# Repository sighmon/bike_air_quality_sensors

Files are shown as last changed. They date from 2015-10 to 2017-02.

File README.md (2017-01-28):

# Bike air quality sensors

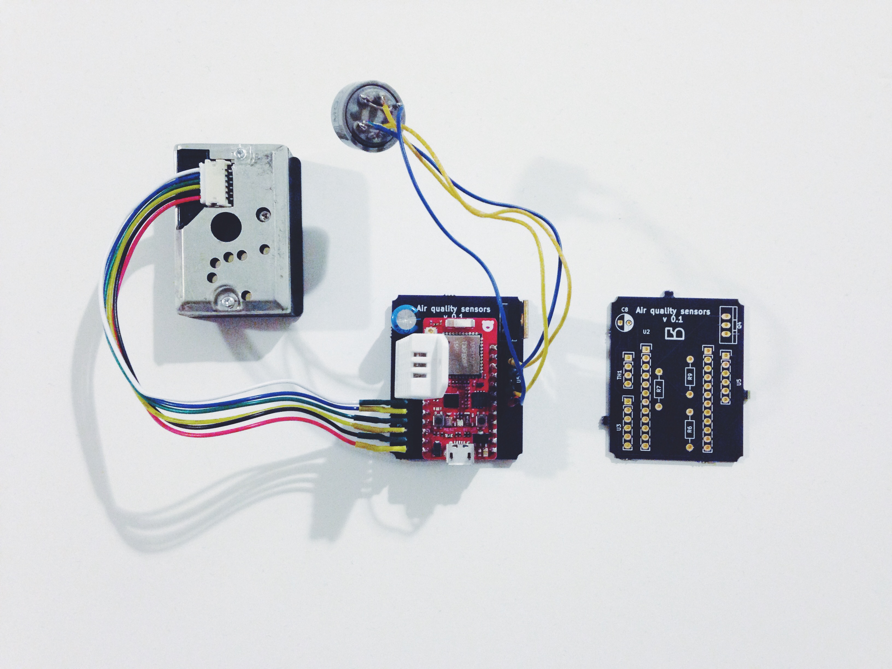
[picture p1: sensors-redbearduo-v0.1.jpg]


A set of Carbon Monoxide & dust particle sensors combined with humidity/temperature sensors for measuring the air quality while cycling.

The sensors are hooked up to an Arduino which then sends the data via serial over Bluetooth to our Android or iOS phone to be time stamped and have GPS data added.

This data will then be sent to a Rails server to graph the data - and also provide an API for others to interact with it.

by Damien & Simon

## Hardware

* [Redbear Duo](https://github.com/redbear/Duo)
* [MQ-7 Carbon Monoxide sensor](https://www.sparkfun.com/products/9403)
* [GP2Y10 Dust Particle sensor](https://www.sparkfun.com/products/9689)
* [DHT-22 Temperature/Humidity sensor](https://www.sparkfun.com/products/10167)
* P-channel MOSFET
* 10K ohm resistor
* 20K ohm resistor
* 150 ohm resistor
* 220µF capacitor

## Output

The sensors are read every second and output in a struct:

`struct SENSOR_READINGS {
    float temperature;
    float humidity;
    float particles;
    float co;
    char heaterOn;
};`

* Temperature in Celsius
* Humidity %
* Dust particle raw sensor value
* Carbon monoxide raw sensor value
* Heater on/off sent as 1 or 0

### Power usage

* When heating the Carbon Monoxide sensor: 200 mA
* When not heating the Carbon Monoxide sensor: 130 mA

### Data from the iOS app with GPS location & timestamp

Google Spreadsheet: [bike sensor data](https://docs.google.com/spreadsheets/d/1QTtR4N6sVxgsv6Za4kGe6Mn_MdasWhGjeMLYdR82Do4/edit?usp=sharing)

[Interactive graph of the data](https://docs.google.com/spreadsheets/d/1QTtR4N6sVxgsv6Za4kGe6Mn_MdasWhGjeMLYdR82Do4/pubchart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)

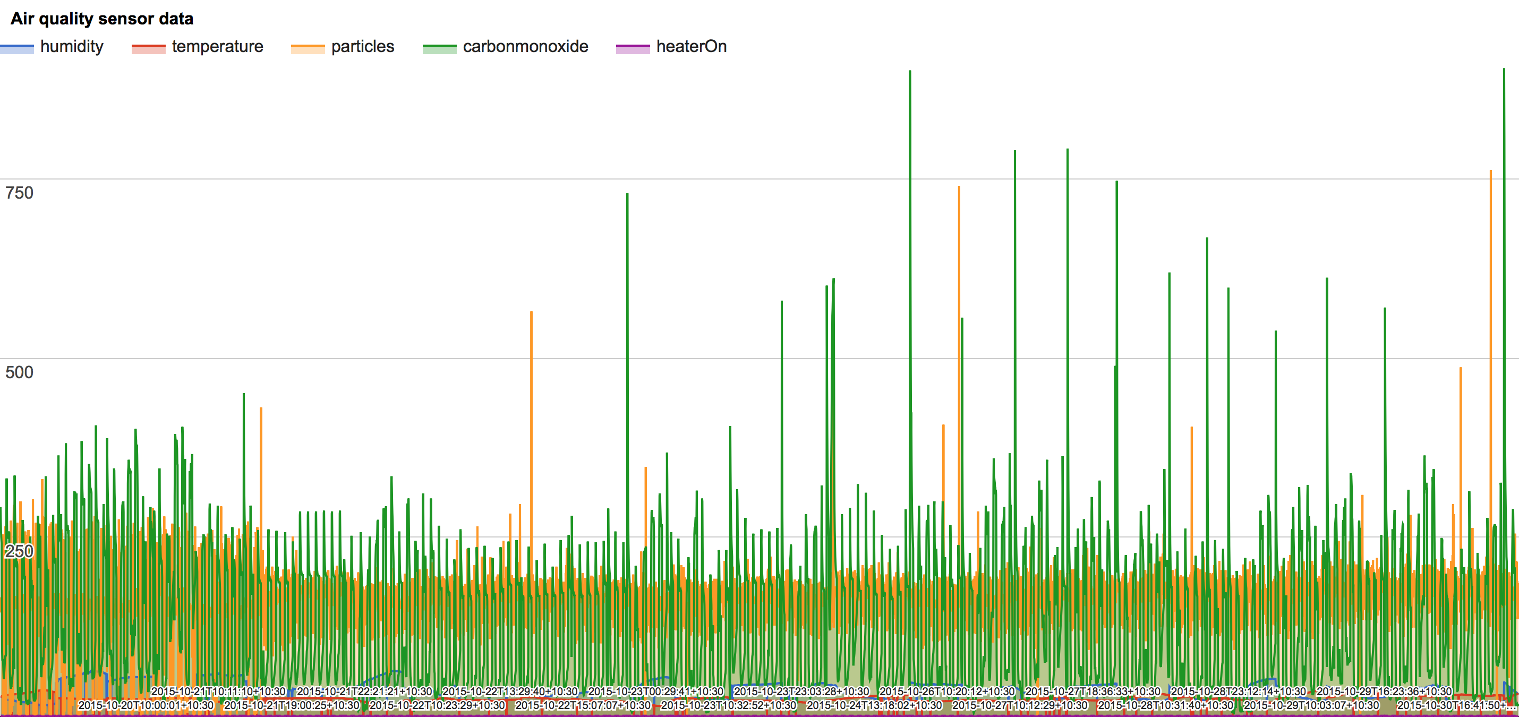
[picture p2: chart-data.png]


## Libraries

Thanks for the DHT sensor library:
<https://learn.adafruit.com/dht/using-a-dhtxx-sensor>

Thanks for the Sharp Optical Dust Sensor library:
<http://arduinodev.woofex.net/2012/12/01/standalone-sharp-dust-sensor/>

MQ-7 Carbon Monoxide sensor:
<http://thesis.jmsaavedra.com/make/>

## iOS & Android apps

[iOS app](https://github.com/sighmon/BikeAirQualitySensorsiOS)

[Android app](https://github.com/33d/bike-air-sensor-logger)

Both apps add:

* ISO 8601 formatted time, including the time zone.
* The position - latitude and longitude.

Then they export the data to a CSV file.

## Python data parser for the CSV

The Carbon Monoxide sensor can only be read after it's been heating for 60 seconds, so we need to throw away all of the data around this.

This Python parser does just that. :-)

<https://github.com/sighmon/bike_air_quality_sensor_csv_parser>

## Manufactured by OSH Park

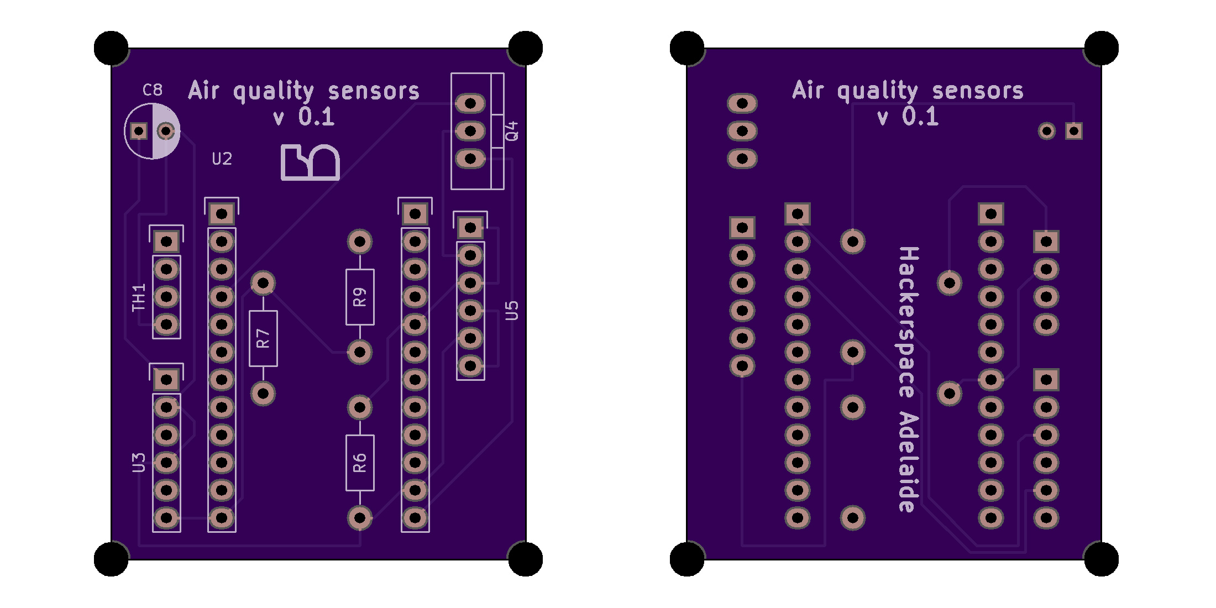
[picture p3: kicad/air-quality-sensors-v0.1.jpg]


I got the first batch of boards manufactured by <https://oshpark.com>. You can see the shared project here: <https://oshpark.com/profiles/sighmon>

## GovHack Machinery of Data entry video

<iframe width="100%" height="315" src="https://www.youtube.com/embed/KiIhrwRlb6w" frameborder="0" allowfullscreen></iframe>

## Troubleshooting

- If the RedBear Duo gets itself into a flashing blue light of doom, hold down both ```reset + setup``` for 3 seconds, then let go of the reset. Hold the setup button until the flashing turns yellow. That’s DFU mode to [re-upload the user firmware](https://github.com/redbear/Duo/blob/master/docs/firmware_deployment_guide.md).

``` $ dfu-util -d 2b04:d058 -a 0 -s 0x80C0000 -D duo-user-part.bin```

## TODO

* <s>Connect sensors to the Arduino.</s>
* <s>Send data via Bluetooth.</s>
* <s>Build an iOS app.</s>
* <s>Build an Android app.</s>
* Build a Rails server to open up the data via a public API.

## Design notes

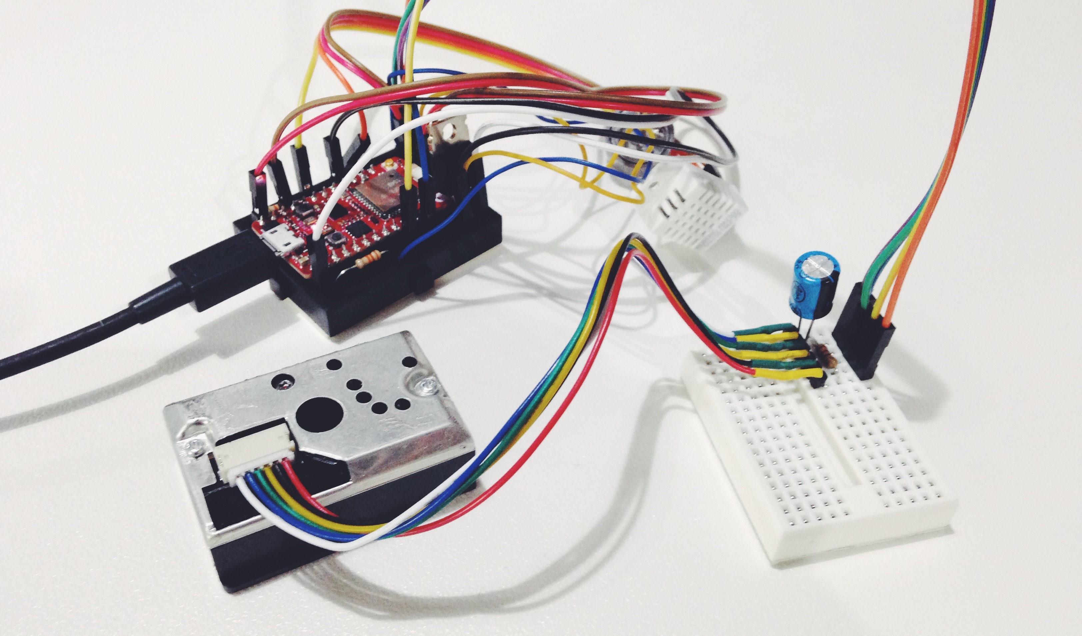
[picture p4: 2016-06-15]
sensors-redbearduo.jpg

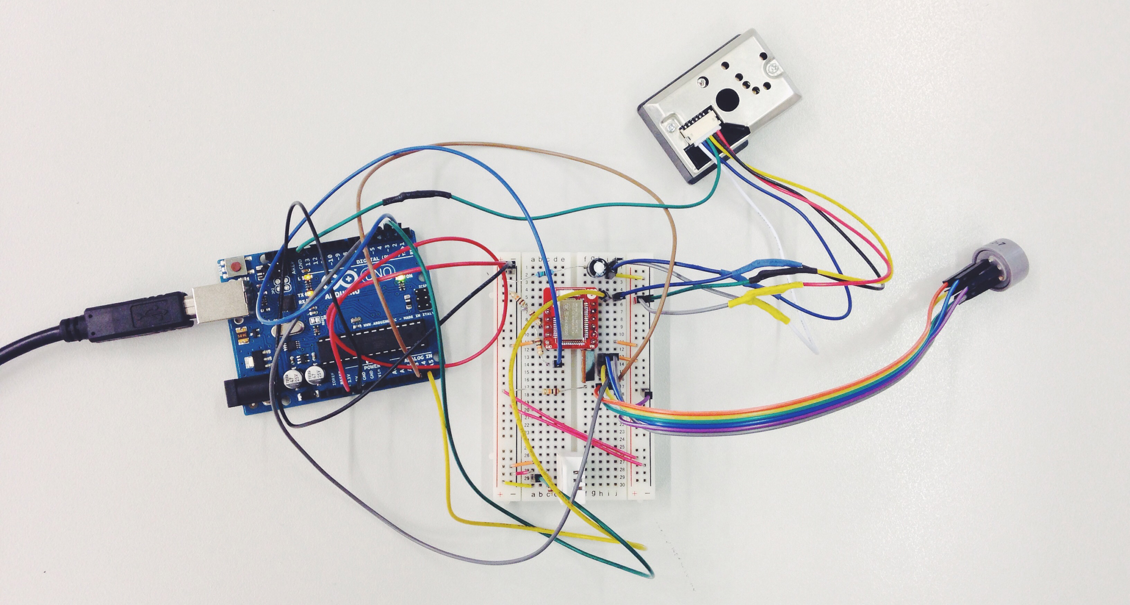
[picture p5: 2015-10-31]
sensors-arduino.jpg

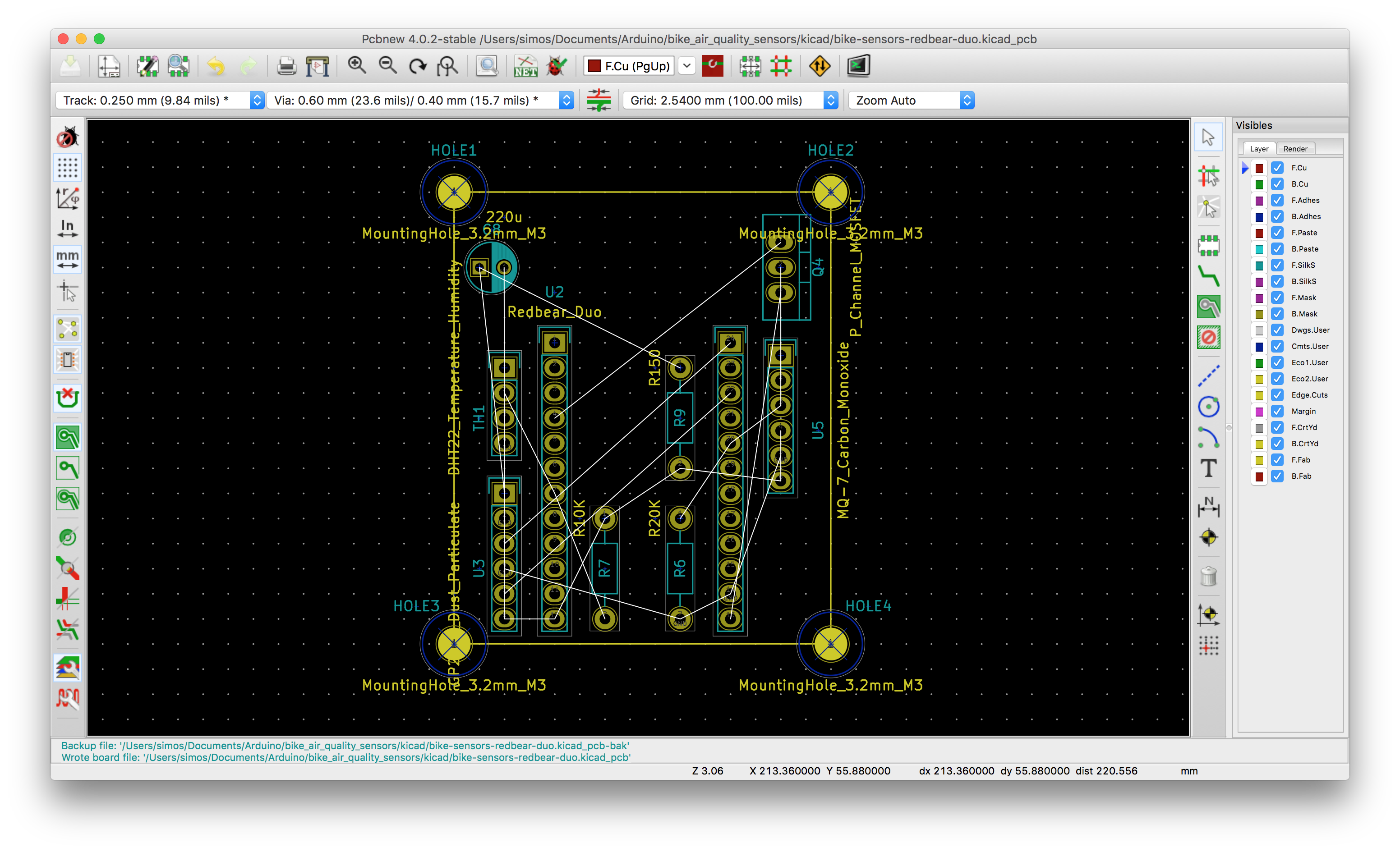
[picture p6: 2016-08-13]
kicad/bike-sensors-board.png

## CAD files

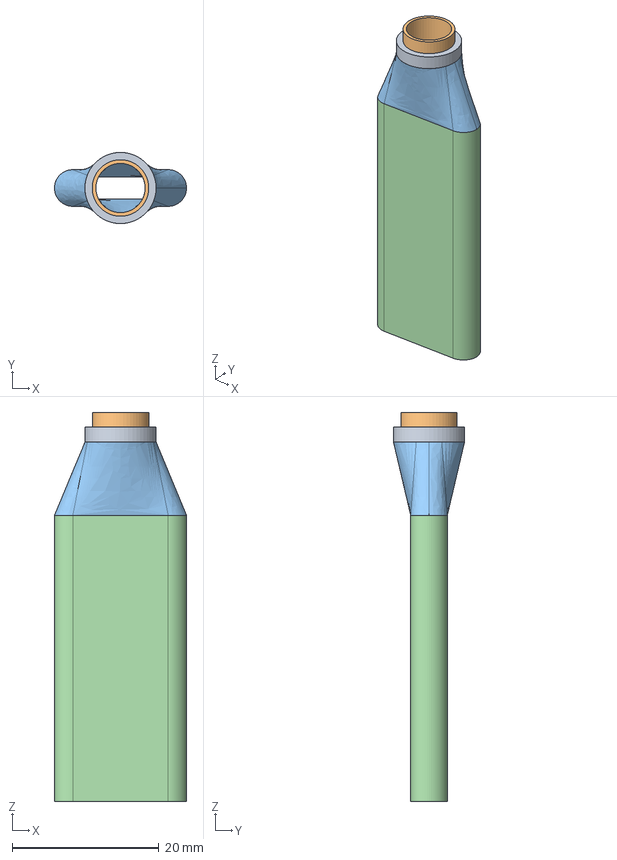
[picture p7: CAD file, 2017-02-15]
freecad/bike_air_sensors_dust_straw_blend.FCStd
18.0 x 9.70 x 53.0 mm

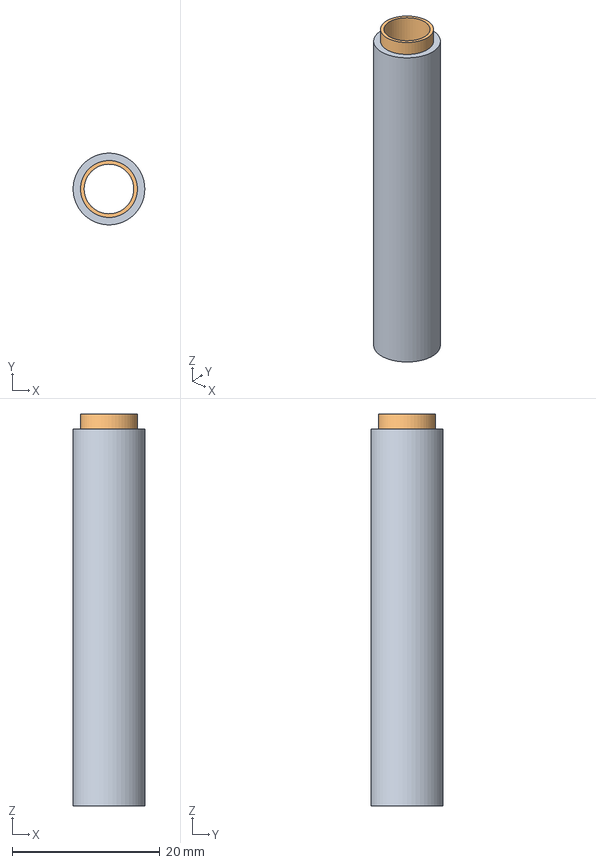
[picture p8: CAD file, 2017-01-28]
freecad/bike_air_sensors_dust_straw.FCStd
9.69 x 9.70 x 53.0 mm

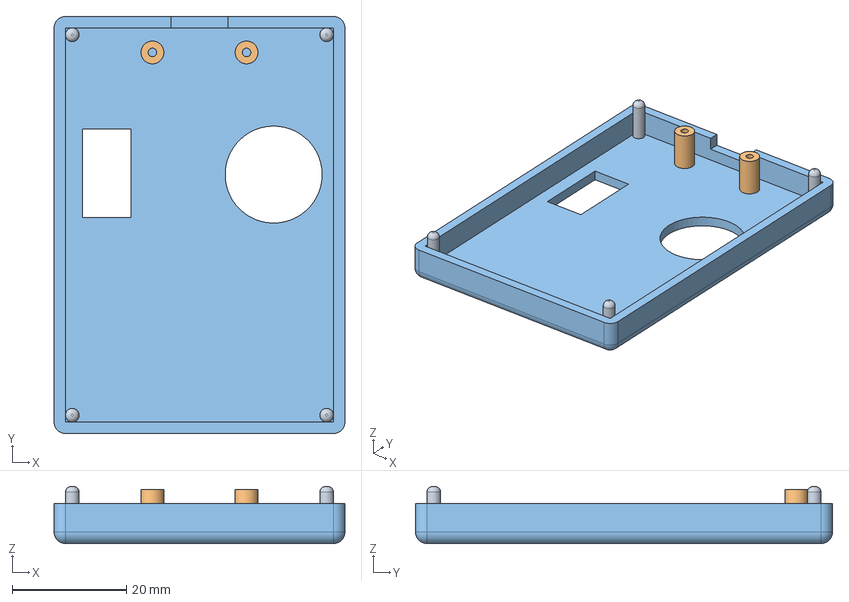
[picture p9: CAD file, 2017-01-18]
freecad/bike_air_sensors_enclosure_top.FCStd
51.0 x 73.1 x 10.0 mm

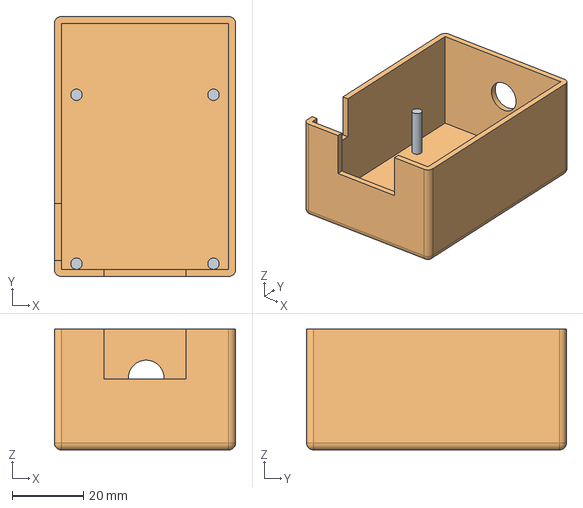
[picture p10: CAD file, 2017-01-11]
freecad/bike_air_sensors_enclosure.FCStd
51.0 x 73.1 x 34.0 mm
Locator pins

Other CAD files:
freecad/bike_air_sensors_dust_straw.stl
freecad/bike_air_sensors_dust_straw_blend.stl
freecad/bike_air_sensors_enclosure.stl
freecad/bike_air_sensors_enclosure_top.stl

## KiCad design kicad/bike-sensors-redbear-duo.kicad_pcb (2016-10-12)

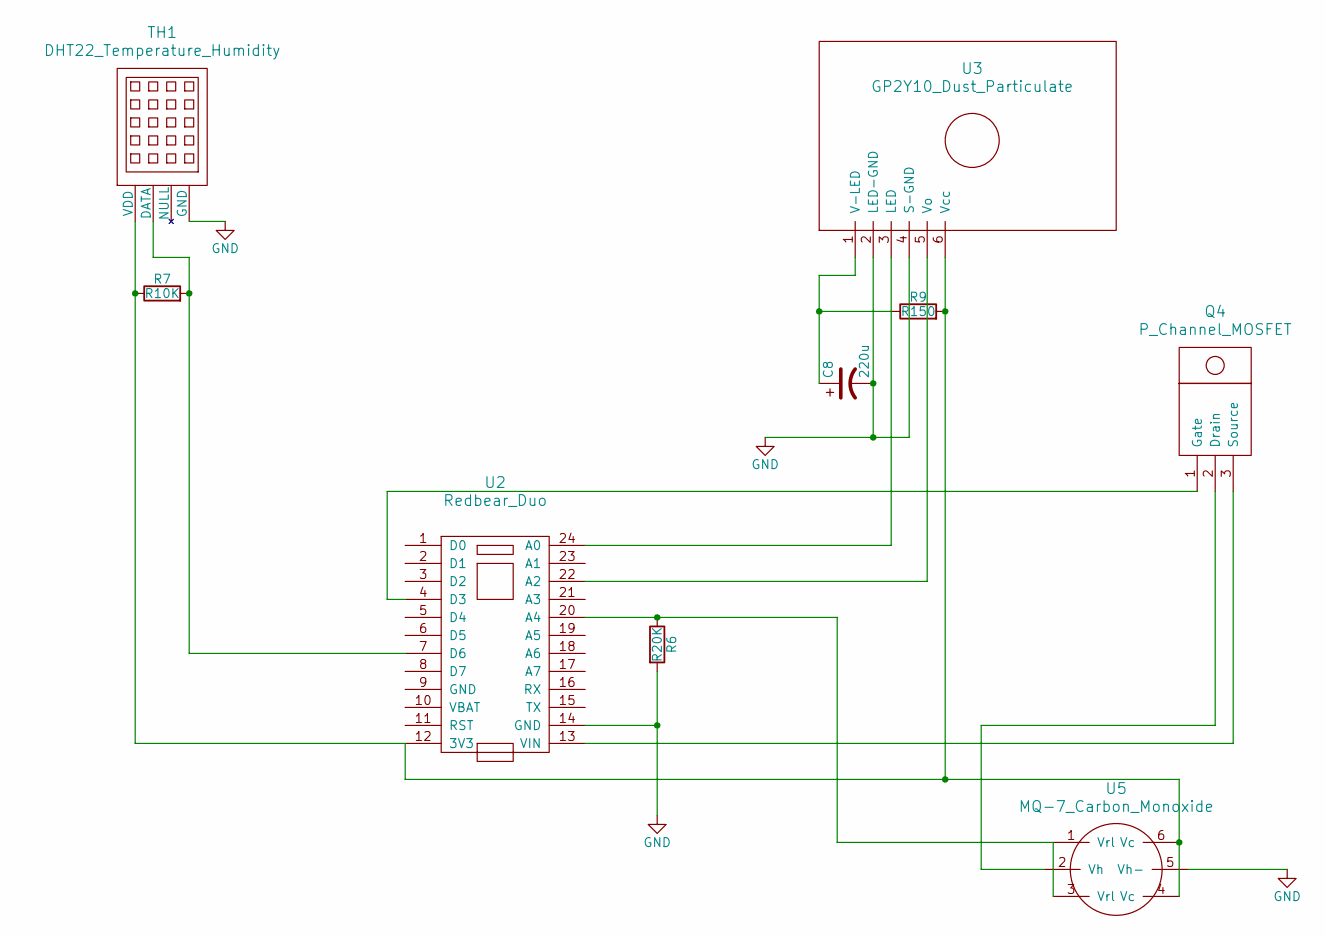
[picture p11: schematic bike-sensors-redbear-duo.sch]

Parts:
C8: 220u
Q4: P_Channel_MOSFET
R6: R20K
R7: R10K
R9: R150
TH1: DHT22_Temperature_Humidity
U2: Redbear_Duo
U3: GP2Y10_Dust_Particulate
U5: MQ-7_Carbon_Monoxide

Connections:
GND: C8.2, R6.2, TH1.4 (GND), U2.14 (GND), U3.2 (LED-GND), U3.4 (S-GND), U5.5 (Vh-)
unnamed: C8.1, R9.1, U3.1 (V-LED)
unnamed: Q4.1 (Gate), U2.4 (D3)
unnamed: Q4.2 (Drain), U5.2 (Vh)
unnamed: Q4.3 (Source), U2.13 (VIN)
unnamed: R6.1, U2.20 (A4), U5.1 (Vrl), U5.3 (Vrl)
unnamed: R7.1, R9.2, TH1.1 (VDD), U2.12 (3V3), U3.6 (Vcc), U5.4 (Vc), U5.6 (Vc)
unnamed: R7.2, TH1.2 (DATA), U2.7 (D6)
unnamed: U2.22 (A2), U3.5 (Vo)
unnamed: U2.24 (A0), U3.3 (LED)

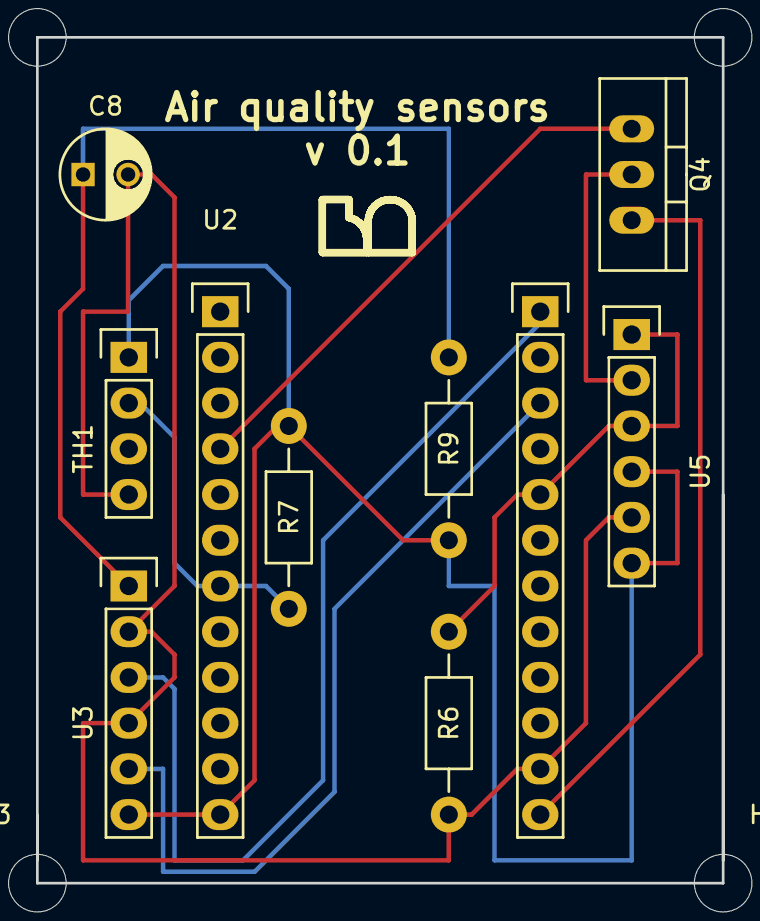
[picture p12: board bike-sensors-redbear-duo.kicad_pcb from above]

Board: 2 copper layers, 38.1 x 47.0 mm, 13 parts (0 on the bottom side), 10 nets.

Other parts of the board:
HOLE1, HOLE2, HOLE3, HOLE4: MountingHole_3.2mm_M3

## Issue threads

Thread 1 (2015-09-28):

Bluetooth/USB OTG with Android

kunguz, 2015-09-28:
Hi, I liked your thinking and the idea behind this project. Wouldn't it be nice to have some additional development on this? I would be more than happy to help in my free time.

- Migrate to Arduino UNO.
- Build an android app. using Kivy (https://github.com/kunguz/yogurt), pyjnius, USB OTG (https://gist.github.com/kunguz/98d2ad7f3ed5a2bb6abe). Thus, all required is a small circuitry attached to the bike. App can even be a service rather than a full one. Circuitry can be powered through USB
- And/Or battery operated operation using a bluetooth serial port such as HC-06.

Let me know, if this sounds interesting. We can discuss further.

Kaan

sighmon, 2015-09-29:
@kunguz Hi Kaan, Damien and I are finishing this for a competition on November 1st - so after that I'd love your help. Our plan is to have an iOS & Android app talking to the Arduino via Bluetooth, but we're avoiding OTG for now because neither of our devices support it.

Thanks for getting in touch - I'll ping you when we're finished the competition.

kunguz, 2015-09-29:
Sounds good! Wish you the best for the competition. Let me know when my help is needed!

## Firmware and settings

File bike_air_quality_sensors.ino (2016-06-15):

/*
  A set of Carbon Dioxide and Carbon Monoxide sensors
  combined with humidity/temperature sensors
  for measuring the air quality while cycling.
  
  by Damien & Simon
  
  Thanks for the DHT sensor library:
  https://learn.adafruit.com/dht/using-a-dhtxx-sensor
  
  Thanks for the Sharp Optical Dust Sensor library:
  Kudos: http://arduinodev.woofex.net/2012/12/01/standalone-sharp-dust-sensor/
  GitHub: https://github.com/Trefex/arduino-airquality/tree/master/Module_Dust-Sensor

  MQ-7 Carbon Monoxide sensor:
  http://thesis.jmsaavedra.com/make/
  
  BLE Redbear Duo
  http://redbear.cc/duo/
  https://github.com/redbear/Duo
  https://github.com/redbear/STM32-Arduino
*/

// **BLE**

// For RedBear Duo don't connect to the cloud.
SYSTEM_MODE(MANUAL);

// Bluetooth connection LED
int bluetoothLED = 7;

#define DEVICE_NAME                "Air quality"

#define CHARACTERISTIC1_MAX_LEN    20
#define CHARACTERISTIC2_MAX_LEN    20

#define TXRX_BUF_LEN               20

/******************************************************
 *               Variable Definitions
 ******************************************************/
static uint8_t service1_uuid[16]       ={0x71,0x3d,0x00,0x00,0x50,0x3e,0x4c,0x75,0xba,0x94,0x31,0x48,0xf1,0x8d,0x94,0x1e};
static uint8_t service1_tx_uuid[16]    ={0x71,0x3d,0x00,0x03,0x50,0x3e,0x4c,0x75,0xba,0x94,0x31,0x48,0xf1,0x8d,0x94,0x1e};
static uint8_t service1_rx_uuid[16]    ={0x71,0x3d,0x00,0x02,0x50,0x3e,0x4c,0x75,0xba,0x94,0x31,0x48,0xf1,0x8d,0x94,0x1e};
// From iOS app
//static uint8_t service1_rx_uuid[16]    ={0x71,0x3D,0x00,0x03,0x50,0x3E,0x4C,0x75,0xBA,0x94,0x31,0x48,0xF1,0x8D,0x94,0x1E,};

static uint8_t  appearance[2]    = {0x00, 0x02};
static uint8_t  change[2]        = {0x00, 0x00};
static uint8_t  conn_param[8]    = {0x28, 0x00, 0x90, 0x01, 0x00, 0x00, 0x90, 0x01};

static uint16_t character1_handle = 0x0000;
static uint16_t character2_handle = 0x0000;
static uint16_t character3_handle = 0x0000;

static uint8_t characteristic1_data[CHARACTERISTIC1_MAX_LEN]={0x01};
static uint8_t characteristic2_data[CHARACTERISTIC2_MAX_LEN]={0x00};


static btstack_timer_source_t characteristic2;

static advParams_t adv_params;
static uint8_t adv_data[]={0x02,0x01,0x06,0x08,0x08,'S','e','n','s','o','r','s',0x11,0x07,0x1e,0x94,0x8d,0xf1,0x48,0x31,0x94,0xba,0x75,0x4c,0x3e,0x50,0x00,0x00,0x3d,0x71};

char rx_buf[TXRX_BUF_LEN];
static uint8_t rx_buf_num;
static uint8_t rx_state=0;


/******************************************************
 *               Function Definitions
 ******************************************************/

 
void deviceConnectedCallback(BLEStatus_t status, uint16_t handle) {
    switch (status){
        case BLE_STATUS_OK:
            Serial.println("Device connected!");
            digitalWrite(bluetoothLED, HIGH);
            break;
        default:
            break;
    }
}

void deviceDisconnectedCallback(uint16_t handle){
    Serial.println("Disconnected.");
    digitalWrite(bluetoothLED, LOW);
}


int gattWriteCallback(uint16_t value_handle, uint8_t *buffer, uint16_t size)
{
//    Serial.print("Write value handler: ");
//    Serial.println(value_handle, HEX);

    if(character1_handle == value_handle)
    {
        memcpy(characteristic1_data, buffer, min(size,CHARACTERISTIC1_MAX_LEN));
        Serial.print("Characteristic1 write value: ");
        for(uint8_t index=0; index<min(size,CHARACTERISTIC1_MAX_LEN); index++)
        {
            Serial.print(characteristic1_data[index], HEX);
            Serial.print(" ");
        }
        Serial.println(" ");
    }
  

    return 0;
}

//void m_uart_rx_handle()
//{   //update characteristic data
//    ble.sendNotify(character2_handle, (uint8_t*)rx_buf, CHARACTERISTIC2_MAX_LEN);
//    memset(rx_buf, 0x00,20);
//    rx_state = 0;
//}

static void  characteristic2_notify(btstack_timer_source_t *ts)
{   

    if (Serial.available()) {
      //read the serial command into a buffer
      
      uint8_t rx_len =min(Serial.available(),CHARACTERISTIC2_MAX_LEN);
      
      Serial.readBytes(rx_buf, rx_len);
      //send the serial command to the server
  
//      Serial.print("Sent: ");
//      Serial.println(rx_buf);
      rx_state = 1;
    }
    if (rx_state != 0)
    {
        ble.sendNotify(character2_handle, (uint8_t*)rx_buf, CHARACTERISTIC2_MAX_LEN);
        memset(rx_buf, 0x00,20);
        rx_state = 0;
    }
    // reset
    ble.setTimer(ts, 200);
    ble.addTimer(ts);
  
}

// **BLE END**

#include <stdio.h>

/**
 * Source: https://chromium.googlesource.com/chromiumos/platform/vboot_reference/+/master/firmware/lib/crc8.c
 * Return CRC-8 of the data, using x^8 + x^2 + x + 1 polynomial.  A table-based
 * algorithm would be faster, but for only a few bytes it isn't worth the code
 * size. */
uint8_t Crc8(const void *vptr, int len)
{
	const uint8_t *data = (uint8_t *) vptr;
	unsigned crc = 0;
	int i, j;
	for (j = len; j; j--, data++) {
		crc ^= (*data << 8);
		for(i = 8; i; i--) {
			if (crc & 0x8000)
				crc ^= (0x1070 << 3);
			crc <<= 1;
		}
	}
	return (uint8_t)(crc >> 8);
}

// Arduino Task Scheduler for reading sensors every 1 second.
// https://github.com/arkhipenko/TaskScheduler
#include <TaskScheduler.h>

void readSensorsTaskCallback();
void coHeaterTaskCallback();

Task readSensorsTask(2000, -1, &readSensorsTaskCallback);
Task coHeaterTask(60000, -1, &coHeaterTaskCallback);
Scheduler runner;

#include <dht.h>
dht DHT;
#define DHT22_PIN 6

struct
{
    uint32_t total;
    uint32_t ok;
    uint32_t crc_error;
    uint32_t time_out;
    uint32_t connect;
    uint32_t ack_l;
    uint32_t ack_h;
    uint32_t unknown;
} stat = { 0,0,0,0,0,0,0,0};


// Sharp Optical Dust Sensor GP2Y10
int measurePin = A2;
int ledPower = D8;
int samplingTime = 280;
int deltaTime = 40;
int sleepTime = 9680;
float voMeasured = 0;
float calcVoltage = 0;
float dustDensity = 0;


// MQ7 Sensor
int pwmPower = D3; // Digital 3
int mqSensor = A4; // Analog 4
float mqReading = 0;
bool heaterOn = false;


struct SENSOR_READINGS {
    float temperature;
    float humidity;
    float particles;
    float co;
    char heaterOn;
};

float readDustSensor();
float readCoSensor();

void readSensorsTaskCallback() {
  struct SENSOR_READINGS readings;
  uint32_t start;
  int chk;
  uint32_t stop;
  // read temperature, humidity
  SINGLE_THREADED_BLOCK() {
    start = micros();
    chk = DHT.read22(DHT22_PIN);
    readings.humidity = DHT.humidity;
    readings.temperature = DHT.temperature;
    stop = micros();
  }
  stat.total++;
  switch (chk)
  {
  case DHTLIB_OK:
      stat.ok++;
      // Serial.print("OK,\t");
      break;
  case DHTLIB_ERROR_CHECKSUM:
      stat.crc_error++;
      Serial.print("Checksum error,\t");
      break;
  case DHTLIB_ERROR_TIMEOUT:
      stat.time_out++;
      Serial.print("Time out error,\t");
      break;
  default:
      stat.unknown++;
      Serial.print("Unknown error,\t");
      break;
  }

  // DISPLAY DATA
  // read particle sensor
  readings.particles = readDustSensor();
  // read CO sensor
  readings.heaterOn = heaterOn ? 1 : 0;
  readings.co = readCoSensor();

  // Send data over BLE
  ble.sendNotify(character2_handle, (uint8_t*) &readings, sizeof(SENSOR_READINGS));
  
  // Print to serial for debugging
  Serial.print("t: ");
  Serial.print(readings.temperature);
  Serial.print(" h: ");
  Serial.print(readings.humidity);
  Serial.print(" p: ");
  Serial.print(readings.particles);
  Serial.print(heaterOn ? " C: " : " c: ");
  Serial.println(readings.co);
//  Serial.print("Data: ");
//  for (int i = 0; i < sizeof(SENSOR_READINGS); i++) {
//    Serial.print(((uint8_t*) &readings)[i], HEX);
//  }
//  Serial.println("");
//  Serial.println("");
//    Serial.println(sizeof(SENSOR_READINGS));
}


float readDustSensor() {
  // Function to read the dust sensor
  
  // Sharp Optical Dust Sensor GP2Y10 loop
  digitalWrite(ledPower,LOW); // power on the LED
  delayMicroseconds(samplingTime);

  voMeasured = map(analogRead(measurePin), 0, 4095, 0, 1023); // read the dust value
  
  delayMicroseconds(deltaTime);
  digitalWrite(ledPower,HIGH); // turn the LED off
  delayMicroseconds(sleepTime); 
  
  return voMeasured;
}


float readCoSensor() {
  // Function to read the Carbon Monoxide sensor
  
  mqReading = map(analogRead(mqSensor), 0, 4095, 0, 1023);

  return mqReading;
}


void coHeaterTaskCallback() {
  // Callback function to heat up the Carbon Monoxide sensor to the right temperature

  if (!heaterOn) {
    analogWrite(pwmPower, 0);
    heaterOn = true;
    RGB.color(100, 0, 0); // Red
    Serial.println("=");
    Serial.println("=Heater is on for 60s");
    Serial.println("=");
    coHeaterTask.setInterval(60000);
    
  } else {
    // Dropping the heater to 1.4v when taking the reading
    analogWrite(pwmPower, (255 - 255*(1.4/3.3)));
    heaterOn = false;
    RGB.color(0, 100, 0); // Green
    Serial.println("=");
    Serial.println("=Heater is off for 90s");
    Serial.println("=");
    coHeaterTask.setInterval(90000);
  }
  
}


void setup() {

  // Set CO heater pin to output
  pinMode(pwmPower, OUTPUT);

  // Set the RGB LED on the RedBear Duo
  RGB.control(true);

  // Set blue LED on the RedBear Duo
  pinMode(bluetoothLED, OUTPUT);
  
  Serial.begin(115200);
   Serial.println("BIKE AIR QUALITY SENSOR");
   Serial.println("=======================");

  // **BLE**

  ble.init();

  ble.onConnectedCallback(deviceConnectedCallback);
  ble.onDisconnectedCallback(deviceDisconnectedCallback);
  ble.onDataWriteCallback(gattWriteCallback);

  ble.addService(0x1800);
  ble.addCharacteristic(0x2A00, ATT_PROPERTY_READ|ATT_PROPERTY_WRITE, (uint8_t*)DEVICE_NAME, sizeof(DEVICE_NAME));
  ble.addCharacteristic(0x2A01, ATT_PROPERTY_READ, appearance, sizeof(appearance));
  ble.addCharacteristic(0x2A04, ATT_PROPERTY_READ, conn_param, sizeof(conn_param));
  ble.addService(0x1801);
  ble.addCharacteristic(0x2A05, ATT_PROPERTY_INDICATE, change, sizeof(change));

  // Battery
  ble.addService(0x180F);
  static uint8_t battery[1] = {0x64};
  ble.addCharacteristic(0x2A19, ATT_PROPERTY_READ, battery, sizeof(battery));

  ble.addService(service1_uuid);
  character1_handle = ble.addCharacteristicDynamic(service1_tx_uuid, ATT_PROPERTY_NOTIFY|ATT_PROPERTY_WRITE|ATT_PROPERTY_WRITE_WITHOUT_RESPONSE, characteristic1_data, CHARACTERISTIC1_MAX_LEN);
  character2_handle = ble.addCharacteristicDynamic(service1_rx_uuid, ATT_PROPERTY_NOTIFY, characteristic2_data, CHARACTERISTIC2_MAX_LEN);
  
  adv_params.adv_int_min = 0x00A0;
  adv_params.adv_int_max = 0x01A0;
  adv_params.adv_type    = 0;
  adv_params.dir_addr_type = 0;
  memset(adv_params.dir_addr,0,6);
  adv_params.channel_map = 0x07;
  adv_params.filter_policy = 0x00;
  
  ble.setAdvParams(&adv_params);
  
  ble.setAdvData(sizeof(adv_data), adv_data);

  ble.startAdvertising();

  // set one-shot timer
  //characteristic2.process = &characteristic2_notify;
  //ble.setTimer(&characteristic2, 500);//100ms
  //ble.addTimer(&characteristic2);

  // **BLE END**
  
  // Task scheduler setup
  // Serial.println("=Setting up tasks");
  readSensorsTask.enable();
  runner.addTask(readSensorsTask);
  coHeaterTask.enable();
  runner.addTask(coHeaterTask);
  
  runner.enableAll();
  
  // DHT setup
  Serial.print("DHT22 LIBRARY VERSION: ");
  Serial.println(DHT_LIB_VERSION);
  
  // Sharp Optical Dust Sensor GP2Y10 setup
  pinMode(ledPower,OUTPUT);
  
}

void loop() {
  
  // Run tasks
  runner.execute();

}

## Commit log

2015-09-19 First tests with the Humidity/Temperature sensor and Dust Particle sensor.
2015-09-23 Added MQ7 wiring pins.
2015-09-26 Added MQ-7 carbon monoxide sensor reading.
2015-09-26 Added TaskScheduler and moved reading sensors to functions.
2015-10-03 Added CRC to the sensor reading lines. Only reading the sensors every 5 seconds now so the humidity and temperature sensor doesnt complain.
2015-10-03 Sensor prints a capital C when the CO heater is on, and a lowercase c when the heater is off. The reading is only meant to be accurate once the heater is off, but we need to test that.
2015-10-07 Outputting sensor data as a struct to fit within 20 byte limit of BLE.
2015-10-14 Updated README to describe the output of sensor data in a struct.
2016-04-02 Added Fritzing wiring diagrams.
    [bike_air_quality_sensors.fzz, bike_air_quality_sensors_damien.fzz]
2016-04-02 Getting it compiling on the RedBear Duo board.
2016-04-30 Now sending sensor data via BLE. Only sending every 80 bytes instead of 20 bytes.
2016-04-30 Trying to work with an ARM compatible DHT22 library: https://github.com/RobTillaart/Arduino/tree/master/libraries/DHTstable
2016-05-25 Doing the sensor readings in SINGLE_THREADED_BLOCK() so that they don't break the ble.
2016-06-04 Hooked up the optical dust sensor to D8 for LED power and A2 for the reading.
2016-06-04 RGB LED on the RedBear Duo now turns red when the CO sensor is heating, and green when it's off.
2016-06-04 Blue LED on the RedBear Duo now lights up when a bluetooth device is connected. Added Battery reading, but not sure how to get that reading on the iOS side yet.
2016-06-25 KiCad pcb files added
    [bike-sensors-redbear-duo.kicad_pcb, bike-sensors-redbear-duo.sch]
2016-07-23 Continued work on the schematic and starting to understand how the footprint works.
    [bike-sensors-redbear-duo.sch]
2016-07-27 Fixed the footprint. The magic was to append my custom RedbearDuo library to the Footprint Libraries Manager.
    [bike-sensors-redbear-duo.kicad_pcb]
2016-08-13 Fixed the resistor junctions.
    [bike-sensors-redbear-duo.kicad_pcb, bike-sensors-redbear-duo.sch]
2016-08-20 Added text to silk screen layer, and simple Hackerspace logo.
    [bike-sensors-redbear-duo.kicad_pcb]
2016-10-12 Manually routed tracks.
    [bike-sensors-redbear-duo.kicad_pcb]
2016-10-12 Fixed the board edge on the bottom. Sent v0.1 off for manufacturing
    [bike-sensors-redbear-duo.kicad_pcb]
2016-10-12 Added manufacturing information and v0.1 board image.
2016-11-12 Added Gerber files generated and image of the manufactured board.
    [bike-sensors-redbear-duo.dsn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]
2016-11-13 Updated the parts list to include resistors and capacitor.
2017-01-07 Added enclosure freecad files.
    [bike_air_sensors_enclosure.FCStd, bike_air_sensors_enclosure.stl]
2017-01-11 Removed support flange.
    [bike_air_sensors_enclosure.FCStd]
2017-01-11 Shortened USB cable gaps.
    [bike_air_sensors_enclosure.FCStd, bike_air_sensors_enclosure.stl]
2017-01-14 Added enclosure top, and updated power usage.
    [bike_air_sensors_enclosure_top.FCStd]
2017-01-14 Added holes and aligning pins.
    [bike_air_sensors_enclosure_top.FCStd, bike_air_sensors_enclosure_top.stl]
2017-01-18 Finished top enclosure.
    [bike_air_sensors_enclosure_top.FCStd, bike_air_sensors_enclosure_top.stl]
2017-01-28 Added a dust straw to avoid dust getting on the boards.
    [bike_air_sensors_dust_straw.FCStd, bike_air_sensors_dust_straw.stl]
2017-02-04 Added a blended straw option.
    [bike_air_sensors_dust_straw_blend.FCStd]
2017-02-15 Finished blended straw.
    [bike_air_sensors_dust_straw_blend.FCStd, bike_air_sensors_dust_straw_blend.stl]
2017-02-15 Updated dimensions.
    [bike_air_sensors_dust_straw_blend.FCStd, bike_air_sensors_dust_straw_blend.stl]
